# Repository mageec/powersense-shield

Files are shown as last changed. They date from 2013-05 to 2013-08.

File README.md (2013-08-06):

powersense-shield
=================

## Power sensing shield for ST Discovery STM32F407VG-based board##

## How to use ##
The boards have been designed using the free Kicad design software, ehich is available at http://www.kicad-pcb.org/display/KICAD/KiCad+EDA+Software+Suite.

Once Kicad is installed, you can open these designs by opening the .pro file in the root directory of the repository.
You will need to add the folder 'kicad' to your library path in the schematic editor and the folder 'kicad/footprints' to your library path in the PCB tool.

#### Acknlowledgments ####

This work is part of the MAGEEC project (http://mageec.org).

Original design by Simon Hollis at University of Bristol (http://www.cs.bris.ac.uk/home/simon/).

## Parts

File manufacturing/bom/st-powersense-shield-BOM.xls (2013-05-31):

St-powersense-shield
Bill of materials
Contact: simon@cs.bris.ac.uk
Key:
Customer supplied
PCBTrain supplied
Not Fitted
 |  | Footprint | Farnell code | Link
P1 | 22 way socket | 11x2row 2.54mm | 1804456 | http://uk.farnell.com/jsp/search/productdetail.jsp?sku=1804456
P2 | 2 way socket | 2x1 row 2.54mm | 1668334 | http://uk.farnell.com/jsp/search/productdetail.jsp?sku=1668334
P3 | 22 way socket | 11x2row 2.54mm | 1804456 | http://uk.farnell.com/jsp/search/productdetail.jsp?sku=1804456
P4
P5
P6
P7
R1
C1 | 0805100nF 50V 10% X7R | 805
C2 | 120610uF 16V 10% X5R | 1206
U1 | MAX4378FASD | SOIC-14 |  | http://www.digikey.com/product-detail/en/MAX4378TASD/MAX4378TASD-ND/471465
Total Parts to fit |  | 6
Unique lines |  | 5

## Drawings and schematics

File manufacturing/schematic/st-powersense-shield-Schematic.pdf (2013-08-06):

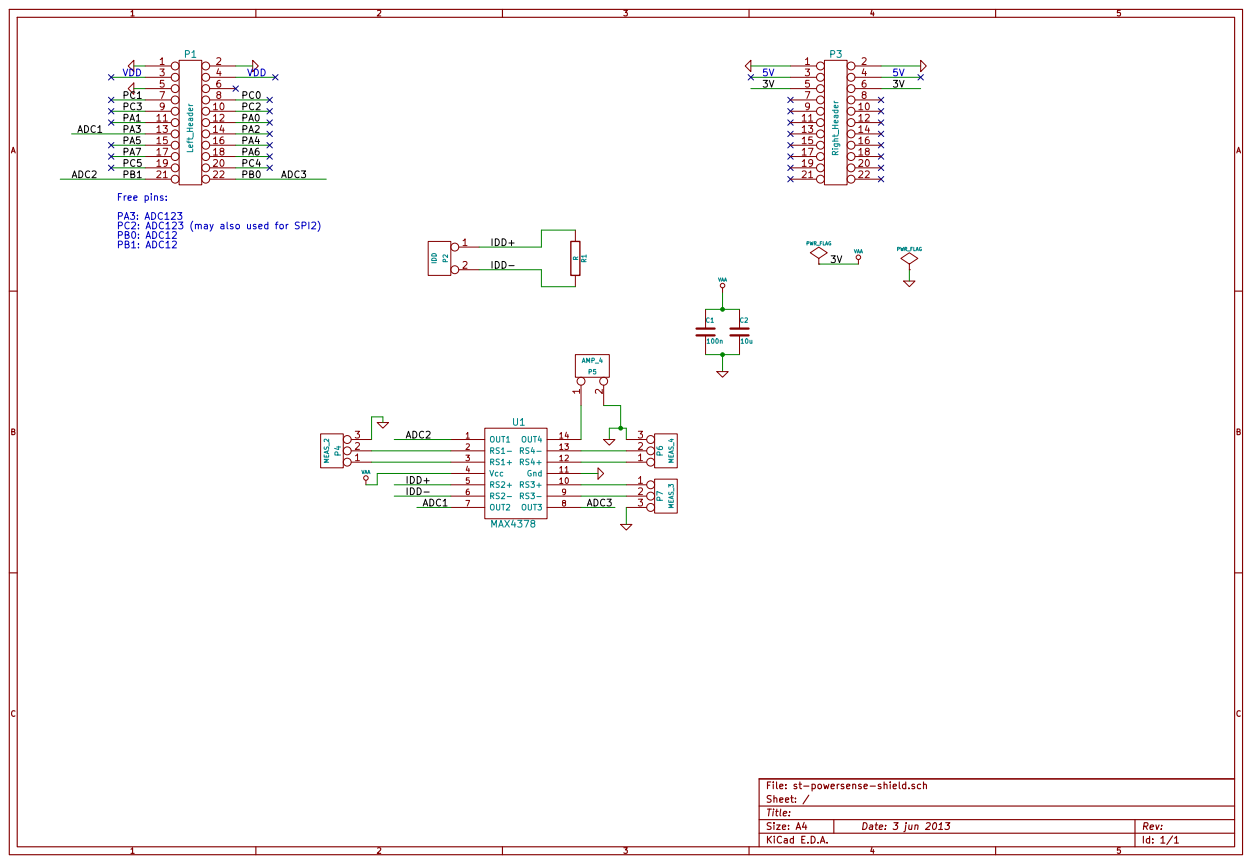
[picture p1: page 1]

Id: 1/1 Title: File: st-powersense-shield.sch
Sheet: /

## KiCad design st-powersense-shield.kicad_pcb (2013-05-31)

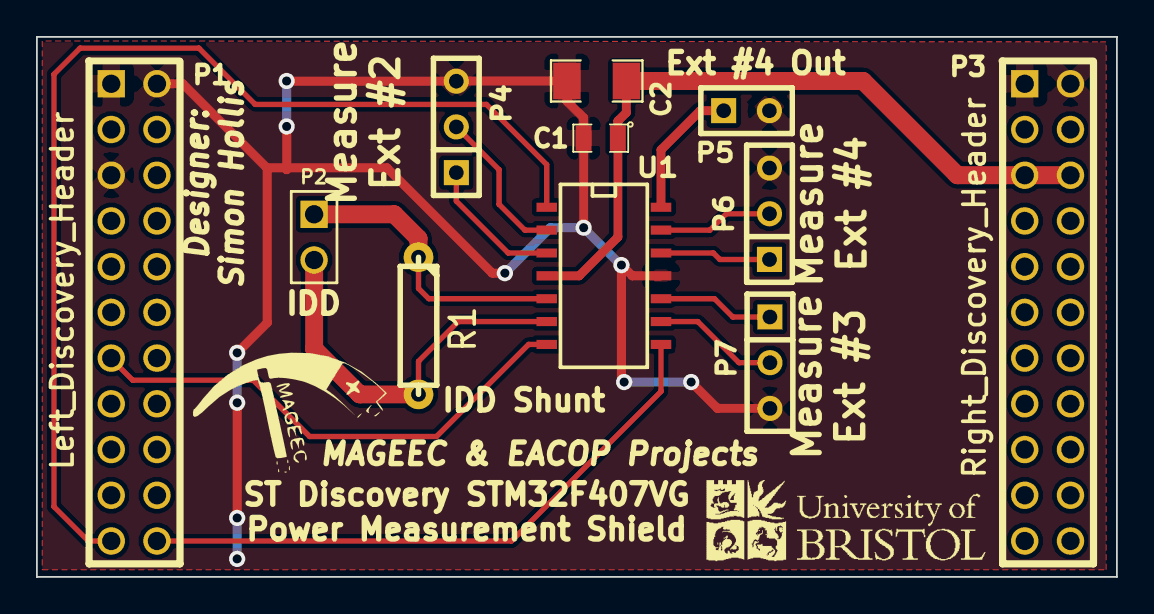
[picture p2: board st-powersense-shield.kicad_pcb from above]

Board: 2 copper layers, 60.0 x 30.0 mm, 11 parts (0 on the bottom side), 16 nets.

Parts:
C1: 100n; SM0805
C2: 10u; SM1206
P1: Left_Discovery_Header; pin_array_11x2
P2: IDD; PIN_ARRAY_2X1
P3: Right_Discovery_Header; pin_array_11x2
P4: MEAS_2; SIL-3
P5: AMP_4; SIL-2
P6: MEAS_4; SIL-3
P7: MEAS_3; SIL-3
R1: R; R3-LARGE_PADS
U1: MAX4378; SO14N

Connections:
/5V: P3.3, P3.4
/ADC1: P1.13, U1.7
/ADC2: P1.21, U1.1
/ADC3: P1.22, U1.8
/IDD+: P2.1, R1.1, U1.5
/IDD-: P2.2, R1.2, U1.6
GND: C1.2, C2.2, P1.1, P1.2, P1.5, P3.1, P3.2, P4.3, P5.2, P6.3, P7.3, U1.11
unnamed: P4.1, U1.3
unnamed: P4.2, U1.2
unnamed: P7.1, U1.10
unnamed: P7.2, U1.9
unnamed: P6.1, U1.12
unnamed: P6.2, U1.13
unnamed: P5.1, U1.14
VAA: C1.1, C2.1, P3.5, P3.6, U1.4
VDD: P1.3, P1.4

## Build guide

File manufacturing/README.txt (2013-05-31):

st-powersense-shield

N.B. ALL THROUGHOLE SOCKETS ARE MOUNTED ON THE REAR. Front silkscreen shows locations.

Build overview
--------------
Size: 60x30mm
2 layer 1.6mm FR4
Solder mask front and back
Silkscreen front only
Assembly front and back
Units in mm

Additional build information
----------------------------

Contact: Simon Hollis
Tel: 0117 3315238
Email: simon@cs.bris.ac.uk
Address: Merchant Venturers Building
Woodland Road
Bristol
United Kingdom
BS8 1UB

PCB Design Tool: KiCad

Description of files included in st-powersense-shield-FAB.zip:

./README.txt    This File

./gerbers/   This directory contains the following gerber files for the design.

st-powersense-shield-F_Cu.gtl	Top Copper Layer 	(Layer 1)
st-powersense-shield-B_Cu.gbl	Bottom Copper Layer 	(Layer 2)
st-powersense-shield-F_Mask.gts	Top Solder Mask
st-powersense-shield-B_Mask.gbs	Bottom Solder Mask
st-powersense-shield-F_Paste.gtp	Top Solder Paste
st-powersense-shield-F_SilkS.gto	Top Silk Screen
st-powersense-shield-Cmts_User.gbr	Comments Layer (for information only)

gerber

./drills

st-powersense-shield.drl	Excellon format drill file, plated holes - Decimal, absolute co-ordinates. Hole size is finished size.
st-powersense-shield-drl_map.pho	Gerber format Drill File (plated through holes)
st-powersense-shield-drl.rpt	Text drill size and number summary

./bom

st-powersense-shield-BOM.xls	Excel format Bill of Materials

./xy/			XY Coponent position data (SMD components front side only; through hole both sides)

st-powersense-shield-XY-Front.csv	XY Component Position Data (Front side) (Comma seperated format)

./netlist/      This directory contains the netlist files for equivalence checking and bare board test.

st-powersense-shield-Netlist.net	Netlist (KiCad format)

./schematic
st-powersense-shield-Schematic.pdf	Schematic (.pdf format)

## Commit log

2013-05-05 Initial commit of design for STM32F407VG Discovery board ADC shield.`
    [st-powersense-shield.kicad_pcb, st-powersense-shield.sch]
2013-05-31 Generated and added manufacturing data. Also added logos to repository.
    [st-powersense-shield-BOM.xls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]
2013-08-06 Updated schematic with originator information.
    [st-powersense-shield.sch]
